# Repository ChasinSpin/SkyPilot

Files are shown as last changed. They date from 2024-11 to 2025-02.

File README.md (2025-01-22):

# Project SkyPilot

## Introduction

Project SkyPilot is a project to design / build / retrofit the C14 in the Wilson Coulee Observation dome with custom goto capabilities.  It leverages all the good parts of the existing mount (Ed Byers Gearing, Fork Mount etc.), whilst bringing it up to date with modern capabilities like:

* Goto (Catalog objects, RA/DEC etc.)
* Computer control
* Mobile phone/tablet control
* Faster slews
* Accurate tracking
* Auto guiding
* Astrophotography
* Dome control

*Although it provides automation, this is not a remote observatory due to safety and the potential for equipment to get damaged, other than control from the site itself.*

## Site

* [Card Access System](auth/README.md)
* Weather - TBA

## Dome:

Access to the dome and C14 is via a $30 yearly fee and instruction on how to operate the dome and C14's goto.

### Users:

* [C14 Goto](goto/README.md)
* C14 Astrophotography - TBA
* [Slit Alarm](dome/SlitAlarm/README.md)
* [GPS](dome/GPS/README.md)
* [PiFinder](pifinder/README.md) (Temporary)

### Site Manager

* [C14 Maintenance](maintenance/C14Maintenance.md)

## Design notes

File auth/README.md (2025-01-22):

# Dome Access

Access to the dome is via an access key (card or fob). To obtain an access key (the first included in your dome fee), contact the Site Manager and arrange pickup.

Please keep the access key safe; if you lose it, the dog eats it, etc., you will be asked for a small donation to the club to get a replacement.

The touchpad for access is the black box with the LED light on the door frame, the area you touch is the "star constellation," not the LED.

Follow the operation instructions below carefully. All accesses are logged, and failure to lock up correctly will result in you being contacted and asked to return to the site immediately to resolve.

# Instructions

## Entering

1. Hold the card/fob for a second or two, flat to the constellation star pattern and a few millimeters away from the touchpad

2. LED will change to mostly on with the occasional flash-off

3. PUSH ON THE DOOR and then pull to open (this is needed because of the pressure of the door seal)

4. Your name will be displayed on the small lower display just inside by the door

5. The door is now unlocked until you relock it, and you can move in and out by just pushing the door.  In this mode (open), it takes very little force to open/close the door, this is normal.

6. Be aware that if there is wind, the door may blow open, put the latch on the door if this is an issue (you likely want to cool the dome/C14 down for viewing anyway)

## Exiting

1. Hold the card/fob for a second or two, flat to the constellation star pattern and a few millimeters away from the touchpad

2. LED will change to mostly off with the occasional flash-on

3. PUSH IN THE DOOR and then pull to check it’s closed (this is needed because of the pressure of the door seal)

4. The door is now locked and armed

5. If you leave without closing correctly, an alarm will be sent to the Site Manager after a period, which will likely result in a phone call to you, and you’ll be asked to go back and lock up.

## Handing Over To Another

If you opened the dome, and someone else is closing, then when you leave, swipe to close yourself and have the person that’s taking over swipe to open.  That way, you’re logged out, and the next person is logged in. Locking up the dome correctly is now the responsibility of the next person.

Never hand over to someone who isn't an authorized dome user.

## Notes

1. The touchpad is on a 3-second lockout so that you can’t enter and exit at the same time.  I.E. After you’ve tapped, if you remove your key card, you have to wait 3 seconds before presenting another or the same card.

2. Currently, you tap to unlock and relock rather than tap every time you open the door like other systems you’ve likely encountered.  The reason is that we don’t want anyone locked out with their vehicle keys or keycards within the building.

3. For fire purposes, anyone inside can always get out by depressing the handle on the inside.

4. There’s an override key in case there's a hardware failure to get in conventionally.  Eric has the location information for the key if needed.

5. On power failure, the system is locked, and a conventional key needs to be used.

6. When using the dome, please do not unplug the system, and check that no one has unplugged it before you leave. The flashing LED on the touchpad indicates the system is powered

7. Cabling will be covered when I get time to make it look cleaner; in the meantime, please don’t rest any chairs against the gear, etc.

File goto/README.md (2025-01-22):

# Goto Notes

## Mount Operation

1. Make sure Dec Drive on forks is pointing East at right angles to the RA base with DEC cable wrapped behind
2. Power on mount
3. Slew to Dec 90 and press "Home Reset"

### SkySafari

1. Goto/Controls changes the slewing speed

## Byers RA Steppper Motor

* [Part Number: 3008-002](https://www.hurst-motors.com/asabsgeared.html)  Reduction ratio 150:1 12V Unipolar
	
	Current: Worm gear has 216 teeth, and the worm gear rotates once evey 6.6666 minutes, sidereal rates is 1440.091s/day.  This is 1.6666 degrees of rotation per tooth (360/216).
	Drive Gear from motor to worm seems like a 2:1 reduction (needs measuring) and drive contains a 150:1 reduction, so total reduction = ~150 x 2 x 216 = 64800:1
		
	* [Drive Link](https://www.cloudynights.com/topic/285415-byers-c14-starmaster-drive-retrofit/)

	* [Telescope Drive Comparisons](https://www.dfmengineering.com/news_telescope_gearing.html)

These are just notes, nothing of any relevance:

* [Dome Control](https://stargazerslounge.com/topic/407704-control-of-dome-to-keep-telescope-in-centre-of-slot/)

## DEC

Strainwave Drive Hollow HBK17 100:1 10arc second backlash
https://www.aliexpress.us/item/1005005920547351.html

Likely a ZWO version of LHS-17-100-CL-III
https://www.leaderdrive.com/strain-wave-gears/lhs-standard-hollow-shaft-flexspline-strain-wave-gear-lhs.asp

*UPDATE THIS*

Nema 17
B62MXL belt 10mm?  Measure and measure the gears in the AM5
Belt:  B62MXL10RF

No brake on Dec

RA: 17D4401-19BK Bipolar (Nema 17)
    • Phase Reistance: 2.30-2.35 Ohm
    • Phase Inductance: 3.7mH @ 1KHz
    • Double shaft with nut on one end: 5mm Diameter
 DEC: 14M3404 Bipolar (Nema 14)
    • Phase Resistance: 7.09-7.21 Ohm
    • Phase Inductance: 7.8-7.9mH @ 1Khz
    • Single shaft: 5mm Diameter, 22mm high

Stepper Drivers: Trinamic TMC5130A-TA 2.5A 5-46V 256 micro step https://www.trinamic...eet_Rev1.18.pdf

Strainwave gear 100:1

Center points are opto interrupted
Reduction 300:1   Stainwave + synchronous belt
Periodic Error <+- 20”
PE Duration 432s
Load Capacitor 13kg
Slew 6 deg/s

Hollow type

https://www.omc-stepperonline.com/hht-series-harmonic-drive-gearbox-70mm-ratio-100-1-backlash-20arcsec-8mm-input-diameter-hht-14-100-i-d8

# Uploading Firmare

1. Open OnStepX.ino in firmware/OnStepX using Arduino 2.3.2
2. Select the port for the Teensy 4.1
3. Connect USB to the Teensy
4. Board should be set to Teensy 4.1
5. Board Settings: Optimize: Faster, CPU Speed: 600MHz, USB Type Serial
6. Compile firmware and upload

## To Wipe NV Ram

Set NV Wipe in Extended.config.h and upload, wait 2 mins, then upload again with NV Wipe Off.

# Mount Startup

1. Set date/location
2. Unpark mount.  (Mount will not be in tracking mode)
3. Slew to NCP
4. Click Home Reset
5. Enable tracking
6. Slew

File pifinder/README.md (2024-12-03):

# PiFinder

## WCO Usage Instructions

*Note: PiFinder is a push-to solution, primarily until the Goto solution is fully implemented. After that, I may remove PiFinder from the scope and use another solution or integrate it into the Goto, that decision hasn't been made yet.*

* **DO NOT:**
	* Remove PiFinder from its' mount, knock or bump it, we want alignment to be maintained for the next user
	* Attempt to use PiFinder without training. PiFinder is password protected, and this is provided at the end of the training.
	* Change any settings other than the settings accessed via the device buttons on the device itself
	* Adjust Focus

## Setup

* Make sure PiFinder has the GPS cable connected and the cable is located such that it cannot be caught by the user as the cable is thin and can be damaged
* Connect USB Power Adapter
* Power on PiFinder and wait for the display to show a menu
* Remove lens cover
* Enter 4 digit pin provided to you, to enable the panel buttons

## Alignment (if needed)

* Put a bright star in the center of the eyepiece
* On "Camera" Screen, press the action button (looks like a STOP symbol, bottom right hand corner of the keypad), and select the same star by pressing the correct number that matches the star. The C14 and PiFinder axis are now aligned

## Connecting Via Sky Safari 7 (Plus or Pro) and selecting target

* Connect to the Wifi PiFinderAP (there's no password).  Note: Androids often need you to wait until a popup appears for the network confirming connection to a network without internet
* Click Scope and Connect in Sky Safari
* Make sure "Lock" is on, so that the screen automatically updates to the telescope position 
* Select target and click Goto. PiFinder comes up with a "Push", press the right arrow on the PiFinder.  Alternatively you can just slew to the target by moving the C14 and watching the current position in SkySafari

## Selecting Target on PiFinder Buttons

* Select "Objects"
* Find the object and press the right arrow

## Moving The Telescope

The PiFinder updates it's position (Alt/Az) when moving the telescope during which the screen is a bit dimmer.  When stationary, a photo is taken, plate-solved, the position updated and screen goes brighter.  A plate-solve always give you an accurate distance to the target.

The arrows are Alt/Az arrows not RA/DEC so can take a bit of practice to get used to, and they are inverted in direction sometimes, so just minimize the numbers on the screen so they are close to zero until you have the object in the eyepiece.

It's possible to get on target without looking through the eyepiece.

## Finish

* Cover lens with lens cover
* Disconnect GPS wire and put in ziploc bag
* Put cover back on GPS connector
* Remove Power adapter from the USB lead and place in ziploc bag
* Place ziploc bag back in the cupboard
* Wrap Grey USB cable losely around the PiFinder without bumping the PiFinder

## SkySafari 7 (Plus and Pro)

PiFinder can also be used with SkySafari on your mobile device via Telescope Control. Telescope Control is only available in SkySafari 7 Plus and SkySafari 7 Pro.

PiFinder will only be available in SkySafari AFTER the 4 digit pin has been entered.

To setup:

* Menu / Settings / Telescope / Presets / Click "Add Preset"
* Select "Other"
	* Mount Type: Alt-Az. GoTo
	* Scope Type: Meade LX200 Classic 
	* Click "Next"
	* IP Address: pifinder.local
	* Port Number: 4030
	* Connect to the PiFinderAp Network in your phones settings. Note: Androids often need you to wait until a popup appears for the network confirming connection to a network without internet
	* Click on "Check Connection Now"
	* If connection verified, click Next, otherwise check the network you're connected to
	* Change Preset name to "PiFinder"
	* Make sure "Set Telescope Time & Location" is UNCHECKED
	* Click "Save Preset"
	* Select "PiFinder" and connect
	* Click on Observe / Scope Display and enable Telrad Circles and Cross Hairs so you can see a target for the current C14 position in SkySafari

A graphical representation of setting up on SkySafari can be found here: [PiFinder SkySafari Setup Instructions](https://pifinder.readthedocs.io/en/main/skysafari.html)

# Everything Below This Point Are Developer Notes:

## Install

* Image PiFinder_2.0.4.img:
	* Set username and password:
		* Username: pifinder
		* Password: <choose>
* Boot PiFinder, screen will have logo on for a few seconds, then disappear, then it will come back, wait for menu to appear.
* Connect to PiFinderAP with WiFi
* ssh pifinder@pifinder.local
* sudo raspi-config
	* Select 3 (Interace Options):
		4: SPI and choose Enable
		5: I2C and choose Enable
* On PiFinder Front Panel:
	* Settings / PiFinder Type: Left
	* Settings / Mount Type: Equatorial
	* Settings / Camera Type: v3 - imx296 cam
	* Settings Wifi Mode: Client
	* Settings Wifi Mode: Access Point
* ssh pifinder@pifinder.local
	* Change main.py in PiFinder/python/PiFinder to add PIN as per CodeChanges
* ssh pifinder@pifinder.local
	* Enable Overlay FS to avoid SD Card Corruption (see below)

**IMPORTANT: PiFinder MUST ALWAYS BE SHUTDOWN IF OVERLAY FS IS OFF TO PREVENT SD CARD CORRUPTION**

## Switch Overlay FS On (Write Protection)

* sudo raspi-config
* Performance Options / Overlay File System:
	* Would you like the overlay file system to be enabled?: Yes
	* The overlay file system is enabled: Ok
	* Would you like the boot partition to be write-protected?: Yes
	* The boot partition is read-only: Ok
	* Finish
	* Reboot

## Switch Overlay FS Off (Writable)

This is a 2 step process, step 1 to switch off the overlay file system and step 2 to switch off boot partition write protection.

* sudo raspi-config
* Step 1: Performance Options / Overlay File System:
	* Would you like the overlay file system to be enabled?: No
	* The overlay file system is disabled: Ok
	* The boot partition is currently read-only. This cannot be changed while an overlay file system is enabled. Ok
	* Finish
	* Reboot
* Step 2: Performance Options / Overlay File System:
	* Would you like the overlay file system to be enabled?: No
	* The overlay file system is disabled: Ok
	* Would you like the boot partition to be write-protected?: No
	* The boot partition is writeable: Ok
	* Finish
	* Reboot

## PiFinder Development

sudo systemctl restart pifinder

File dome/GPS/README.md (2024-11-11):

# GPS

## Introduction / Usage

**Please replace the yellow connector covers when connectors are not in use to prevent corrosion or dust.**

The dome now has 2 external active GPS antennas, which are available for connecting to, located on the pier, primarily for time and timing purposes. 

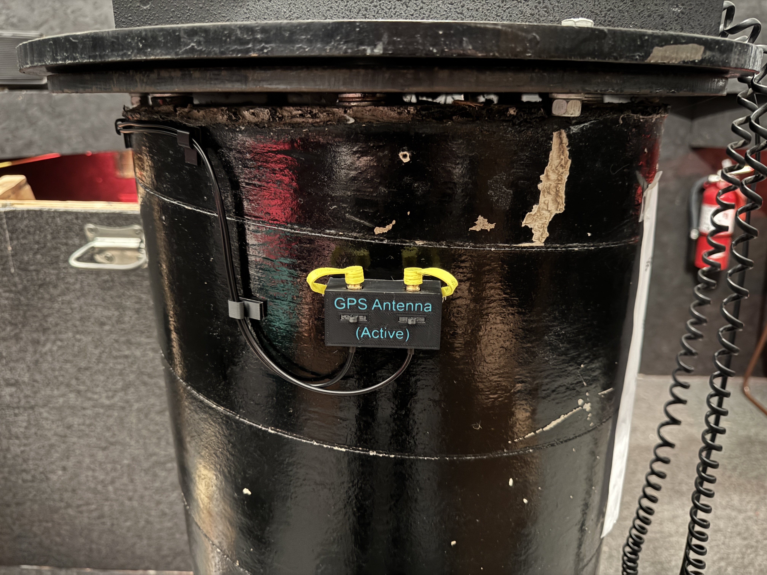
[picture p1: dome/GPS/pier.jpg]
GPS Antenna On Pier


Because the dome is made of metal, it's difficult to get a reliable GPS signal within the dome without an external antenna.

One connection is for the OnStepX Goto Mount Controller (to provide date/time), and the second is for other use (typically Asteroid / Lunar Occultation Timing for Astrid or QHY174GPS). The connections end in an SMA Female connector, and a male-to-male SMA lead that will reach from there to the OTA can be found in a ziploc bag in the lens cupboard.

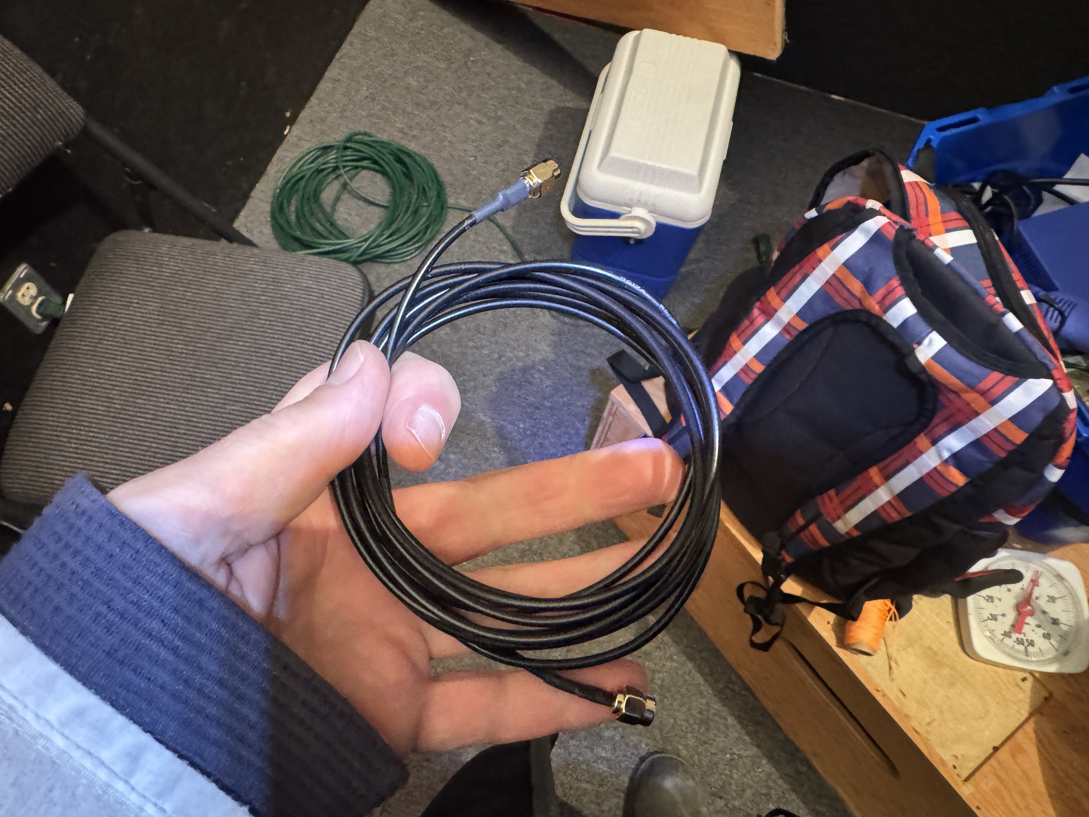
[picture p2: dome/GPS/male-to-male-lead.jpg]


## Repair

### Overview

The antennas are located on the exterior to the left above the door, wired around the inside of the door frame and into the room underneath the dome, across the ceiling, and up the pier. 

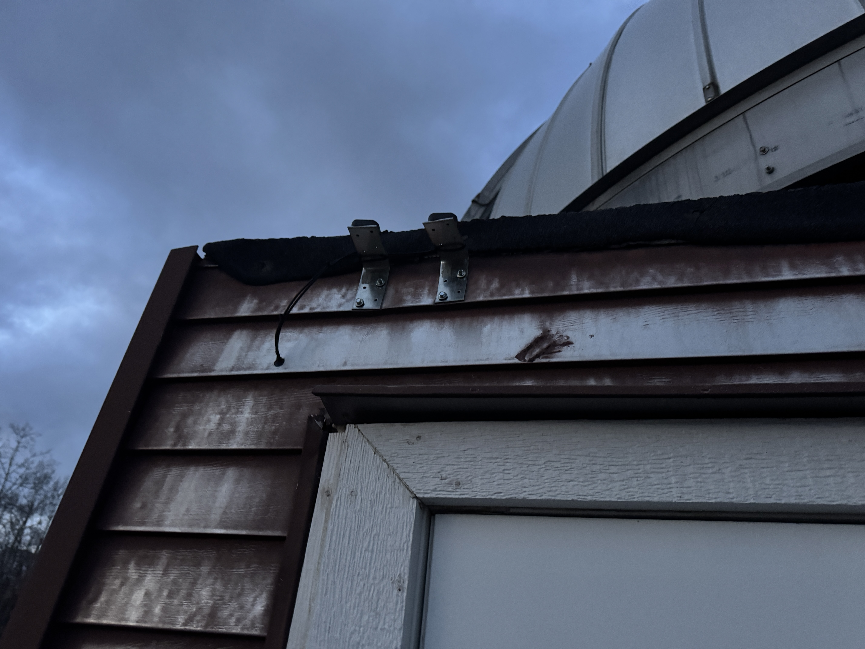
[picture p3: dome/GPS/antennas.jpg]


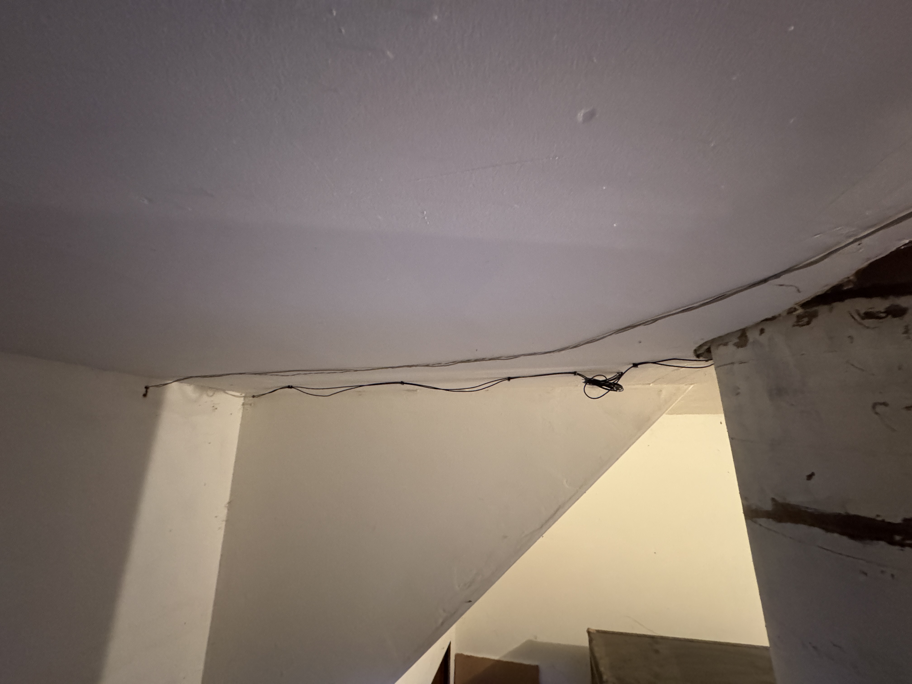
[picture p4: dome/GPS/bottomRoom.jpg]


### Antenna Replacement
 
There is a Male/Female SMA connector on each lead that's covered in heat shrink that can be found midway down the lefthand side of the door frame looking from the inside.  This is the connection point to replace the Active GPS Antenna, if it ever gets damaged by Hail etc.  Purchase information for the GPS antenna is:  [Bingfu Vehicle Waterproof Active GPS Navigation Antenna with SMA Male Connector](https://www.amazon.ca/dp/B07R7RC96G).  If the antennas are replaced, please be sure to recaulk the holes.

### Pier Connector Damage

The pier connectors contain a male-to-female adapter as a sacrificial connector in case of damage [Boobrie SMA Male to SMA Female Connector](https://www.amazon.ca/dp/B07FKNMPKD). To replace, use a pliers or piece of wire to pull out the tab holding the connector assembly in place and pull the wire out from the bottom, the connector will follow. Ensure new connector is tight and that all the Hex Nuts are in line with each other. Test fit the tab before placement, and put tab in after placement.

### 3D Printed Parts

3D printed files can be found in this folder. Clips and Bracket are mounted with 3M Extreme Mounting Tape. Bracket uses 2 x M3 Threaded Inserts, and 2 short M3 bolts and washers to attach the TPU covers to the the sides.

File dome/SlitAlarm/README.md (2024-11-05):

# Slit Alarm

## Introduction

In bad weather or in case of equipment failure, the motor controlling the slit in the WCO dome can re-engage if power is left on to the slit.  This can lead to significant damage (motor burnout or worse).

It is quite common for power to be left on by users due to forgetting to return the slit switch back to neutral after the bottom limit switch has been reached and the movement has stopped.

## Alarm

An alarm has been installed to solve this issue and consists of a 110V AC buzzer and red light, which activates during slit closure.  If the user forgets to switch off the slit power by returning the switch to neutral, the buzzing continues as a reminder to the user to return the switch to normal.  It only activates on slit closure, not on opening, it is up to the user to remember on opening, as the user is present, this is less critical than after the user has left.

The alarm has been installed in an external metal box that is grounded to the main switch box. The 110V for the switch is supplied via 2 contacts in the main switch box, which are engaged to 110V when the slit is being closed. The part number for the alarm is [uxcellAC/DC 110V 20mA Equipment Alarm Signal Indicator Light Flash Buzzer](https://www.amazon.ca/dp/B015SK2OM8?ref=ppx_yo2ov_dt_b_fed_asin_title) and is CE rated.

https://github.com/user-attachments/assets/1f60c342-2444-4560-9f1b-39a3ea6fde14

Photo of the inside of the alarm box. Box contains 110V to the switch + Ground to the box, To remove power, unplug the lead powering slit.  Electrical tape has been added to cover a small part of the exposed ring terminal if the case is open.  Buzzer is place on top and under a wooden overhang to prevent bumping by users when push items like the stairs around the dome.

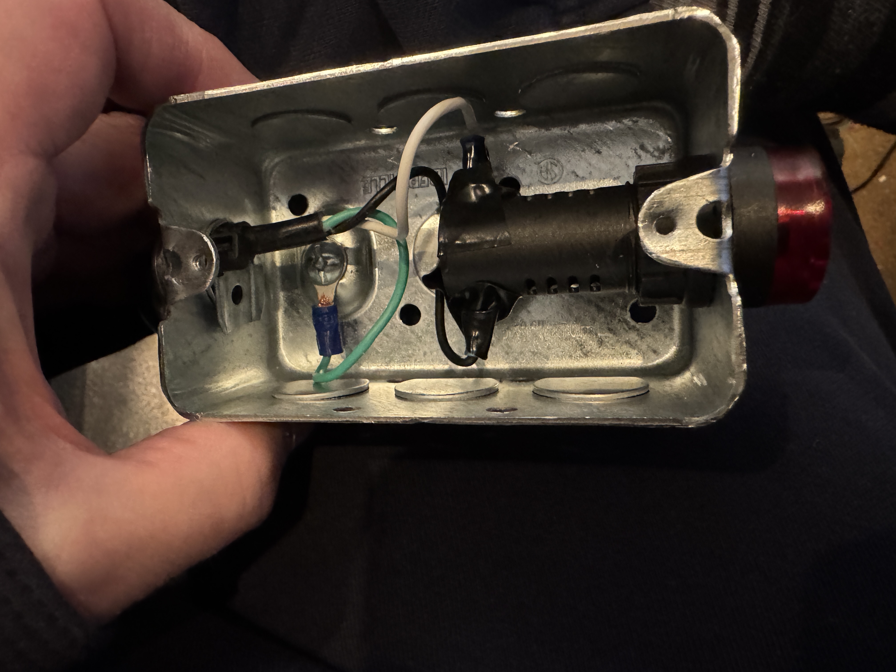
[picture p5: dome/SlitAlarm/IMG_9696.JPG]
Inside Box


Please note that if servicing the main switch, the metal case is grounded by a lead and ring terminal that is trapped between the case and case screw (same as before).  Important to ensure this ring terminal is installed correctly to maintain grounding on both the switch case and the alarm case.  Always check grounding to both cases after reassembly.

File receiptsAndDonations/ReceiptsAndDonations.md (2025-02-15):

# Wish List (Astrophotography)

The following is a list of items that will improve the club's C14 as a resource for astrophotography and outreach / member use.  If you can help in anyway, it would be appreciated by members.

## Phase 1 - Add "Goto" to the C14 (Completed)

Build a custom goto system for the C14 to turn manual operation into automated with goto and auto-guiding capability.  Designed by Mark Simpson using 3D printed parts and a strainwave gear for declination, it leverages the manual mount/fork structure for durability and adds motion to both axis.

This phase has been completed.  Resolution is 0.25 arc seconds, and guiding is 0.5 arc seconds which is better than the 2 arc seconds needed for astrophotography.

## Phase 2 - Plate Solving (Completed)

Plate solving is needed for accurate targeting of objects. This phase uses a guide camera on the Orion ST80 combined with an ASIAIR to provide plate solve ability. When Phase 2 is complete, the guide camera will be repurposed into a guide camera and the main camera will be doing the plate solving. 

| Item | Price | 
| ---- | ----- |
| [ZWO ASIAIR PLUS 256GB (ZWO-AIRPLUS-256)](https://all-startelescope.com/products/zwo-asiair-plus-256gb-zwo-airplus-256) | $424.58 |
| [ZWO ASI174Mini Monochrome Astronomy Camera (ASI174MINI)](https://all-startelescope.com/products/zwo-asi174mini-usb2-0-mono-asi174mini) | $566.58 CAD | 
| [ZWO Finder Shoe for ASIAIR PRO and Guide Scope (ZWO-FS-II)](https://all-startelescope.com/products/zwo-zwo-fs) | $25.56 CAD |

This has been donated to the club by Daniel and Nancy Boychuk.

## Phase 3 - Astrophotography (Completed)

This is to be used on C14 main optical axis @3910mm and @2300mm (with f/6.3 focal reducer). It's a one shot color (OSC) camera. It provides the ability for club members to take astrophotography data/images/scientific research on the clubs C14.

| Item | Price | 
| ---- | ----- |
| [ZWO ASI2600MC Pro  ASI2600MC-P](https://all-startelescope.com/products/zwo-asi2600-pro-usb3-0-cooled-color-astronomy-camera-asi2600mc-p) | $2128.58 CAD |
| **TOTAL (inc. shipping and tax)** | $2289.61 CAD |

Additional to this phase is the flat panel which has already been purchased via club donations, when it was on discount at Christmas.

## Phase 4 - Add Accessibility and Outreach, Cold Weather Tours, Widefield Astrophotography (Completed)

The astrograph will be piggybacked on the C14 and provides widefield capability for imaging at 264mm focal length and f/4.8.

It also adds the capability for outreach and accessibility, as the output of the camera attached to the astrograph, can be streamed to the clubhouse large screen TV and a TV screen inside the dome.

The aiming-device is a pan/tilt for the astrography to align it with the main optical axis.

| Item | Price | 
| ---- | ----- |
| [Askar SQA55 Quintuplet Refractive Astrograph](https://all-startelescope.com/products/askar-sqa55-quintuplet-refractive-astrograph-sqa55) | $1079.95 CAD |
| [ADM Mini-MAX ALT/AZ Aiming Device. Male Dovetail Version](https://www.admaccessories.com/product/mini-max-altaz-aiming-device-male-dovetail-version/) | $339.00 USD ($574.58 CAD) |
| **TOTAL (inc. shipping, tax, duties)** | $1872.55 CAD |

## Phase 5 - Add Narrowband (HA, SII, OIII) on C14 and Widefield (Completed)

There are newer filters now available which can provide good narrowband imaging on one shot color cameras.  This setup is for 2 filters (HA/OIII dual band and SII/OIII dual band) than can be used to provide 3 band data for narrowband imaging.

Narrowband imaging produces sharper and better imaging for Planetary Nebula, Emission Nebula and Planetary forming regions of Galaxies.

Narrowband imaging is immune to light pollution and moonlight:

* WCO is in Bortle 5 skies (which is fairly heavy light pollution), in narrowband, targets are the same as if you were in a bortle 1 or 2 skies. It's possible to image also in the northern part of the sky, or towards Okotoks, where the light domes are worse.
* It's possible to image during a full moon without gradients when positioned at least 90 degrees away from the moon. The results are the same as a moonless night.

The following are the 2 filters, a bracket to hold the widefield scope and backfocus adjustment spacer for the imaging train.

| Item | Price | 
| ---- | ----- |
| [ADM Accessories Dovetail Plate Adapter (DPA)](https://all-startelescope.com/products/adm-dovetail-plate-adapter) | $82.95 CAD |
| [ZWO M48(male)-M48(female) extender (16.5mm length)](https://all-startelescope.com/products/zwo-m48male-m48famale-extender16-5mm-length-zwo-m48-ext16-5) | $32.66 CAD |
| [Askar Color Magic D Duo-Band Filters - D1](https://all-startelescope.com/products/askar-colour-magic-d-duo-band-filters-colour-magic-d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) | $401.95 CAD |
| [Askar Color Magic D Duo-Band Filters - D2](https://all-startelescope.com/products/askar-colour-magic-d-duo-band-filters-colour-magic-d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) | $401.95 CAD |
| **TOTAL (inc. shipping and tax)** | 983.87 CAD |

*Short by: $13.87*

## Phase 6 - Accessories (Completed)

Accessories to complete the system. Filters holders and drawer (3 for filters and 1 for blanking off for broadband). Celestron 48mm back focus assembly for native focal length imaging.  Flat Panel for piggybacked astrograph.

| Item | Price | 
| ---- | ----- |
| 3 x [ZWO Filter Holder V2](https://davidastro.com/products/zwo-filter-holder-v2) | See below |
| [ZWO Filter Drawer V2](https://davidastro.com/products/zwo-filter-drawer-v2-m54) | See below |
| [Celestron 48mm T-Adapter for EdgeHS 9.25", 11", 14"](https://davidastro.com/products/celestron-48mm-t-adapter-for-edgehd-9-25-11-and-14) | See below |
| Total David's Astro (inc GST and shipping) | $400.80 CAD |
| [M48x0.75 extension tubes](https://www.amazon.ca/dp/B0BSGHFX44?ref_=pe_125682630_1045605200_fed_asin_title) | $12.60 CAD |
| [Camera Holder/Cover](https://www.amazon.ca/dp/B00VZYRKNA) | $25.66 CAD |
| [SCT-M48 Adapter - Williams Optics - D-SCT-TA](https://williamoptics.com/products/sct-m48-adapter?_pos=1&_sid=63479adb4&_ss=r) | $96.48 CAD ($67.00 USD exchange rate 1.44) |
| [Astrophotography 5in EL Panel Circle Flat Frame Kit]() | $194.40 CAD |
| **TOTAL (inc. shipping and tax)** | $729.94 CAD |

## Phase 7 - Electronic Focusing (Completed)

To simplify focusing in general and to achieve pinpoint focusing for astrophotography (which is hard to achieve manually with a 14" SCT), it would be beneficial to have electronic focusing for the C14 and piggybacked Sharpstar 76 EDPH.

For the C14, as it's visual too, we would require a hand controller. For both scopes,  temperature sensors would be useful to trigger automatic refocusing on temperature changes.

| Item | Price | 
| ---- | ----- |
| 2 x [ZWO EAF 5V Electronic Automatic Focuser (ZWO-EAF-5V)](https://all-startelescope.com/products/zwo-eaf) | $423.16 CAD |
| 1 x [ZWO Temperature Sensor of EAF (ZWO-EAF-SENSOR)](https://all-startelescope.com/products/zwo-temperature-sensor-of-eaf-zwo-eaf-sensor) | $28.12 CAD |
| 1 x [ZWO EAF Bracket for Celestron C11 & C14 (ZWO-EAF-C11-C14)](https://all-startelescope.com/products/zwo-eaf-bracket-for-celestron-c11-and-c14-zwo-eaf-c11-c14) | $55.38 CAD |
| 1 x [ZWO Temperature Sensor of EAF (ZWO-EAF-SENSOR)](https://all-startelescope.com/products/zwo-temperature-sensor-of-eaf-zwo-eaf-sensor) | Donated by Jerry |
| 1 x [ZWO Hand Controller for EAF (ZWO-EAF-HC)](https://all-startelescope.com/products/zwo-hand-controller-of-eaf-zwo-eaf-hc) | Donated by Jerry |
| **TOTAL (inc. shipping and tax)** |  $275.94 CAD |

All-Star Telescope have paid for 50% of the items in Phase 7.

## Other
| Item | Price | 
| ---- | ----- |
| iPad for those that don't have iPhones | an older iPad is fine |
| Charger |  |

# Donations

| Person | Date | Item | Amount |
| --- | ---- | ---- | --- |
| Khalid Qureshi | 2024-11-27 | 50% Flat Panel and $25.65 towards strainwave gear for DEC| $200.00 |
| Vinh Vo | 2024-11-28 | 50% Flat Panel | $174.35 |
| Alan K Chan | 2024-12-02 | Part payment towards OnStepX Controller components | $125 |
| Mike Rossier | 2024-12-23 | Part payment towards strainwave gear for DEC | $150.00 |
| Daniel & Nancy Boychuck | 2025-01-29 | ASIAIR Plus 256, ASI174MM, Finder Shoe | $1086.99 (via donation to club) |
| Mike Rossier | 2025-01-31 | Part payment toward Askar Filter - D1 | $250.00 |
| Jerry Medeiros | 2025-02-01 | Part payment towards Askar Filter - D1 and D2 | $300.00 |
| Vinh Vo | 2025-02-01 | Part payment towards Askar Filter - D2 | $120 |
| Eric Klaszus | 2025-02-01 | Part payment towards Askar Filter - D2 | $200 |
| Alan K Chan | 2025-02-02 | ADM Adapter Plate and M48 Extender | $100 |
| Terry Martin | 2025-02-02 | Various items. ZWO 2600MC-Pro, Sharpstar 76EPDH + Focal Reducer, Alt-Az Mount, Vixen, L-Extreme, Rings, M54 Adapters | $4824.22 |
| Submitted to Nisha - up to this point | - | - | - |
| Jerry Medeiros | 2025-02-13 | Focuser Hand Controller and temperature sensor | $84.78 |
| Bill Yeung | 2025-02-13 | Payment of Phase 6 + Phase 7 and $26.41 towards magnetic charging cable| $1032.29 |
| Mark Simpson | 2024-11-01 - Present | SkyPilot Goto | $1069.36 |
| All-Star Telescope | 2025-02-14 | 50% Towards Phase 7 | $246.30 |
| Trevor Gauthier | - | Planetary Camera | TBD |
| Bruce Foster | - | f/6.3 Japan Focal Reducer | TBD |
| Maciek | - | Airplay units for Android | TBD |
| **TOTAL** | | | $9716.99 |

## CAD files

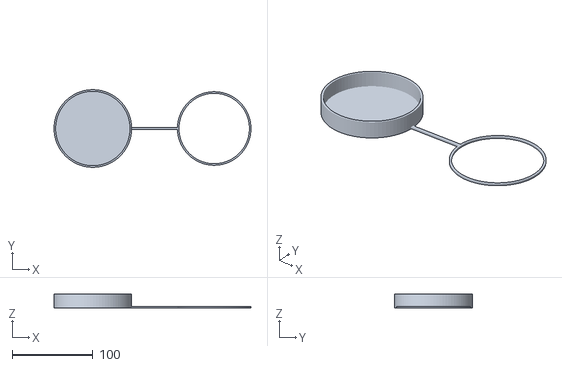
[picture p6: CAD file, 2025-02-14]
dome/C14SilverFinderScopeCover/C14SilverFinderScopeCover.stl
243.5 x 96.0 x 17.0

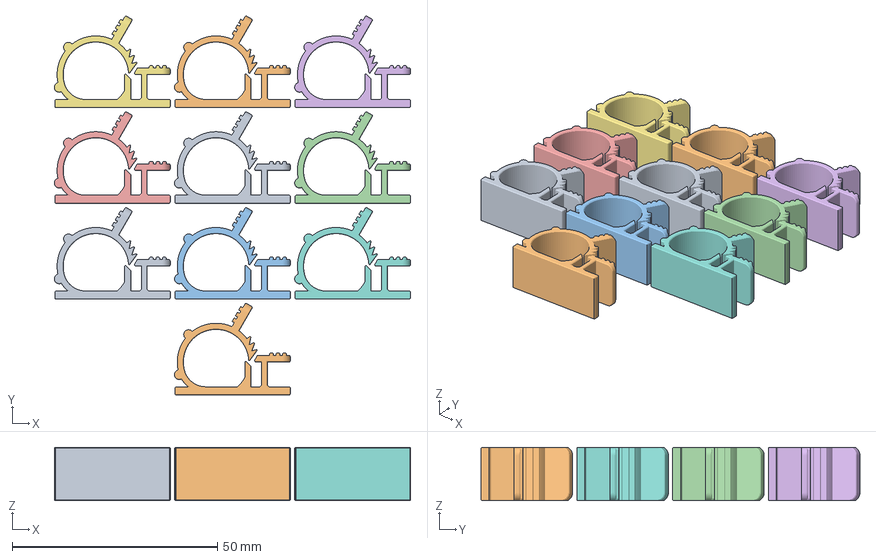
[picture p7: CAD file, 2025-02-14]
dome/CableClip/small wall clip v1.3mf
86.9 x 92.4 x 13.0 mm

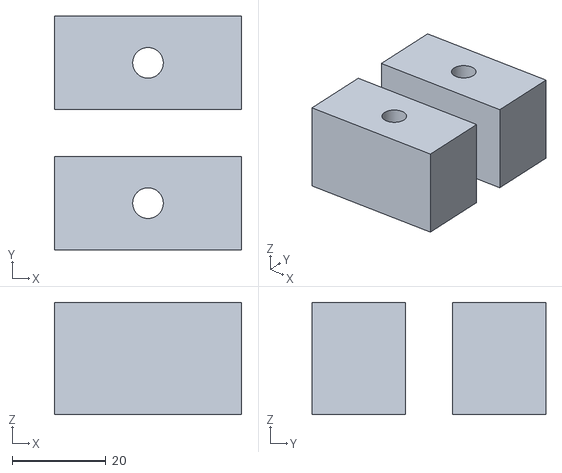
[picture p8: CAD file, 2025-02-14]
dome/CGERailEndStop/CGERailEndStop.stl
40.0 x 50.0 x 24.0

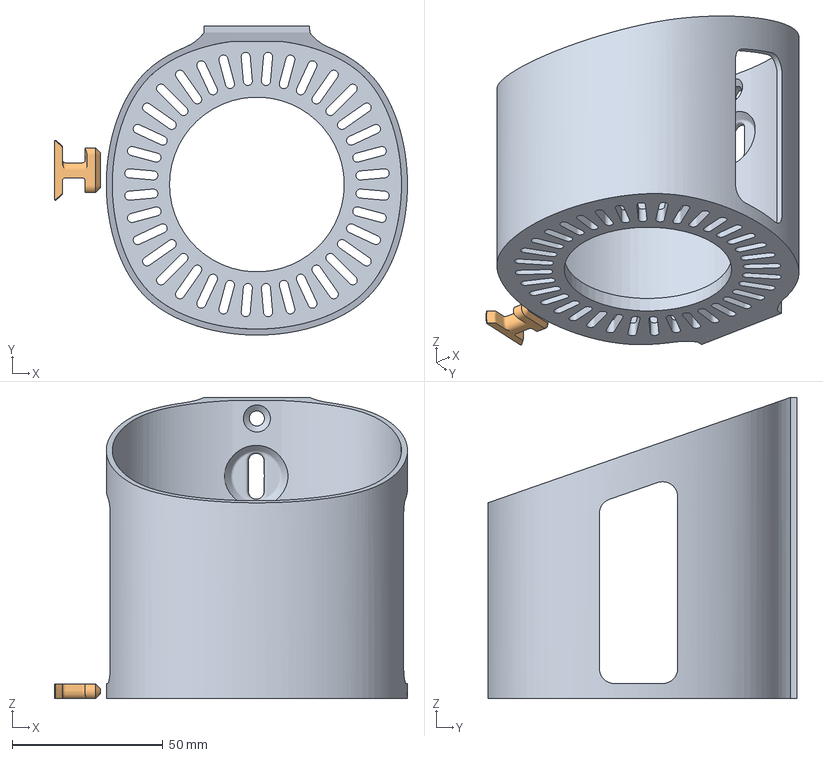
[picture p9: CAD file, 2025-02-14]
dome/DecoM4/DecoM4Holder.3mf
117.2 x 102.7 x 100.0 mm
TP+Link+Deco+M4+T-Clip+Skadis+Holder.stl
T-Clip for Painted Skadis (Flush).STL

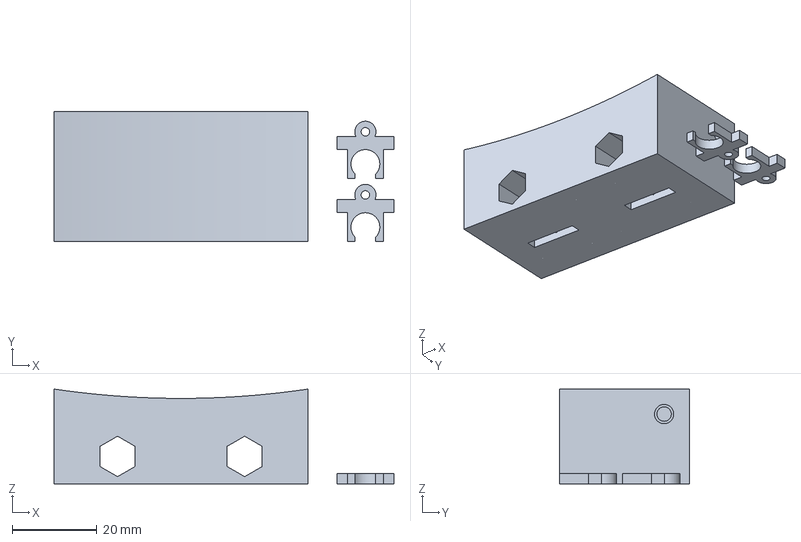
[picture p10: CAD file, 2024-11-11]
dome/GPS/GPSBracket.3mf
80.2 x 30.7 x 22.4 mm

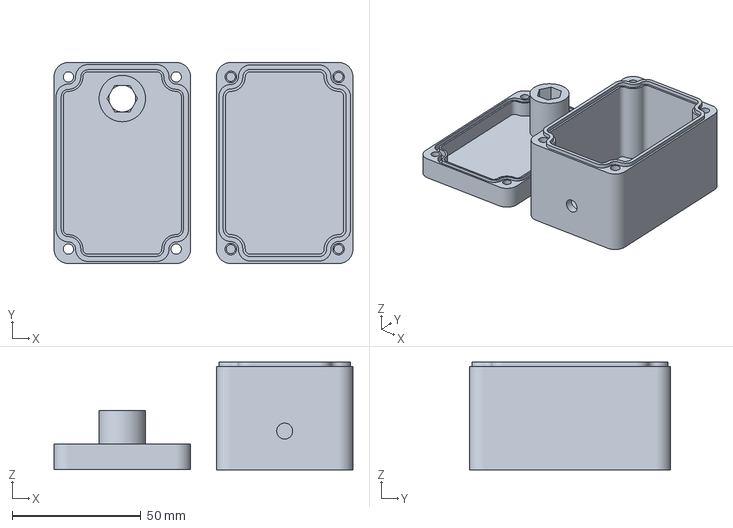
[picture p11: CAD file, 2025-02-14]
dome/Power12V/Power12V.3mf
116.0 x 78.0 x 41.7 mm

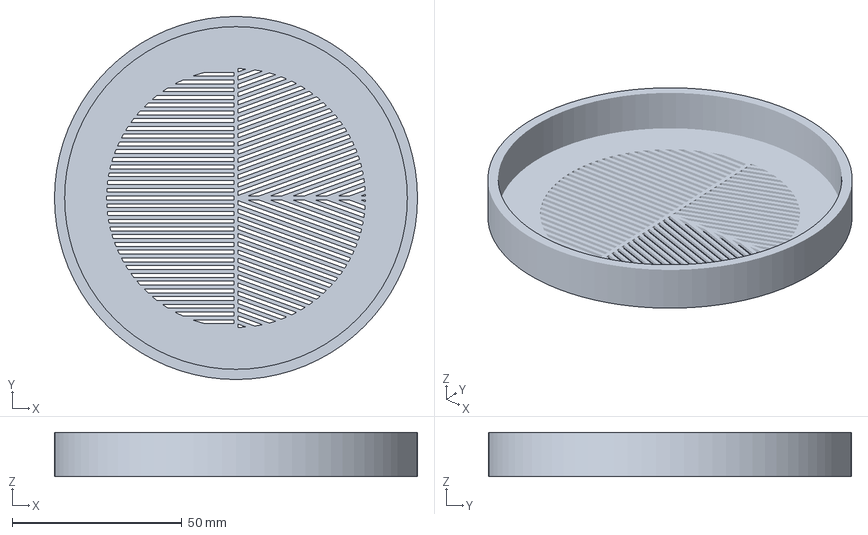
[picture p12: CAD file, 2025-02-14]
dome/Sharpstar76EDPHBahtinov/Sharpstar76EDPHBahtinov.3mf
107.0 x 107.0 x 13.0 mm

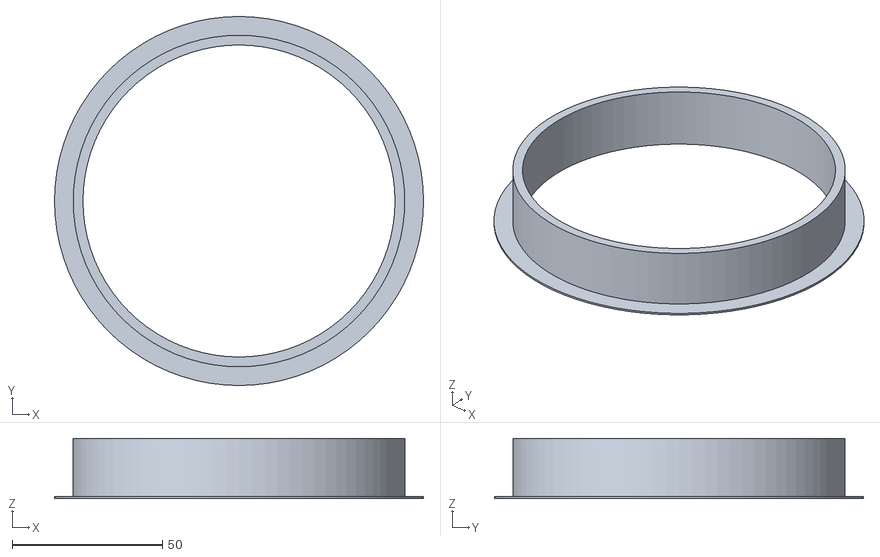
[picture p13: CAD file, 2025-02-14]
dome/TriBahtinovMask_ClubC14/TriBahtinovCenterSupport.stl
123.0 x 123.0 x 20.0

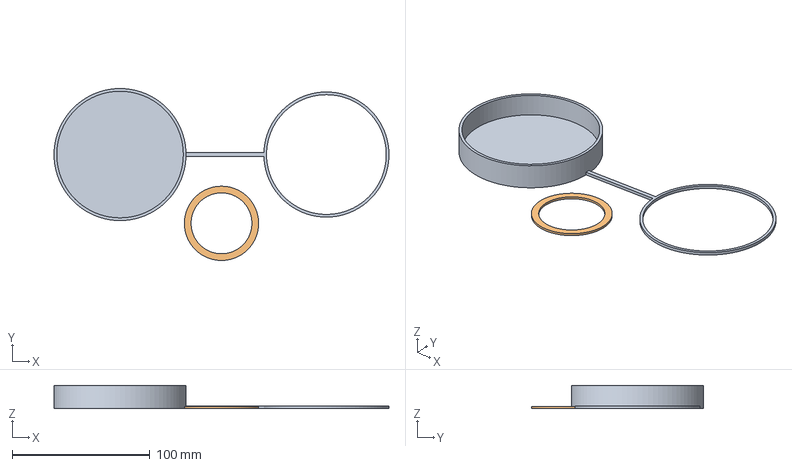
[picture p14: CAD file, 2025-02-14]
dome/ZWOCameraCoverGromit/ZWOCameraCoverGromit.3mf
243.5 x 125.0 x 17.0 mm
C14SilverFinderScopeCover.stl
ZWOCameraCoverGromit.stl

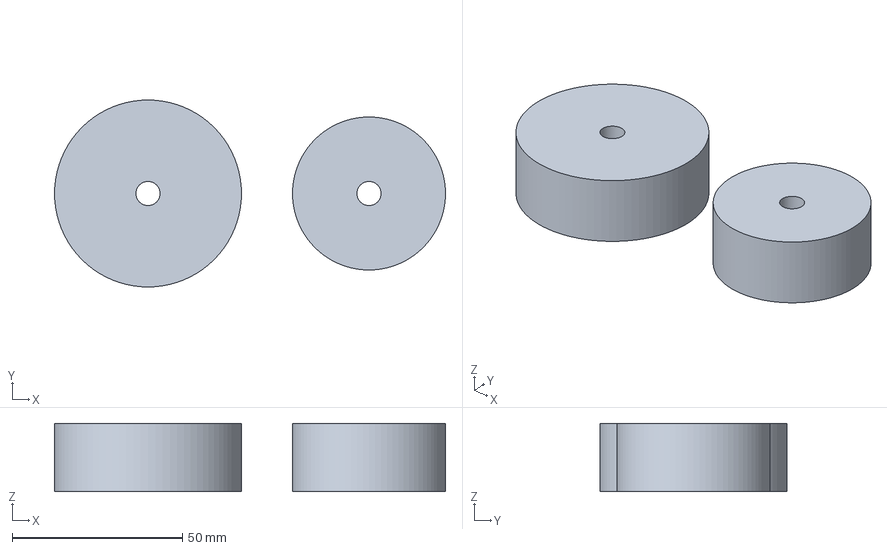
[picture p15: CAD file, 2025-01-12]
doors/DoorHoleFiller.3mf
115.0 x 55.0 x 20.0 mm

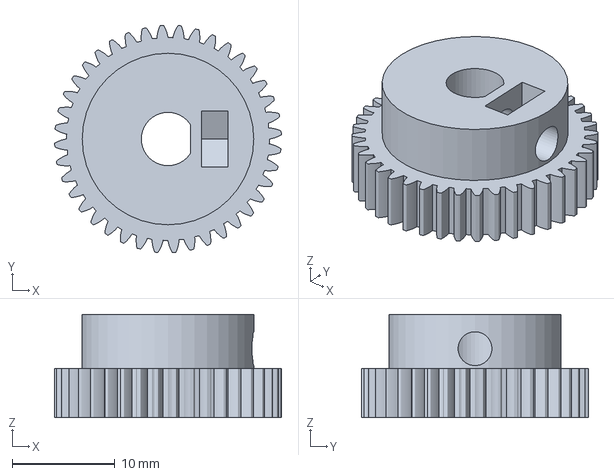
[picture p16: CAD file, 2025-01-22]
goto/3DPrinted/byersDriveGear.3mf
22.1 x 22.1 x 10.1 mm

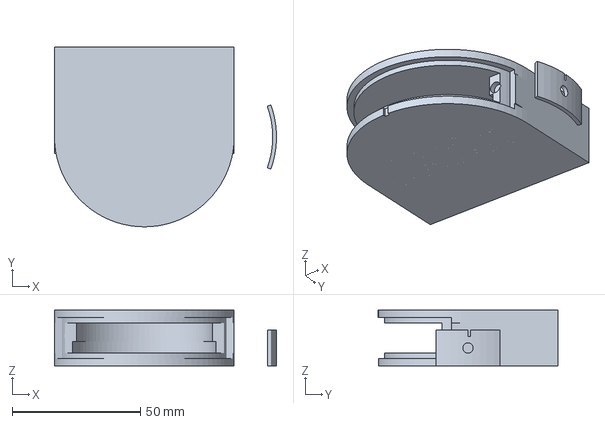
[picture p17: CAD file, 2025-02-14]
imaging/3DPrinting/ZWOFilterCase/ZWOFilterCase.3mf
86.5 x 70.0 x 21.8 mm

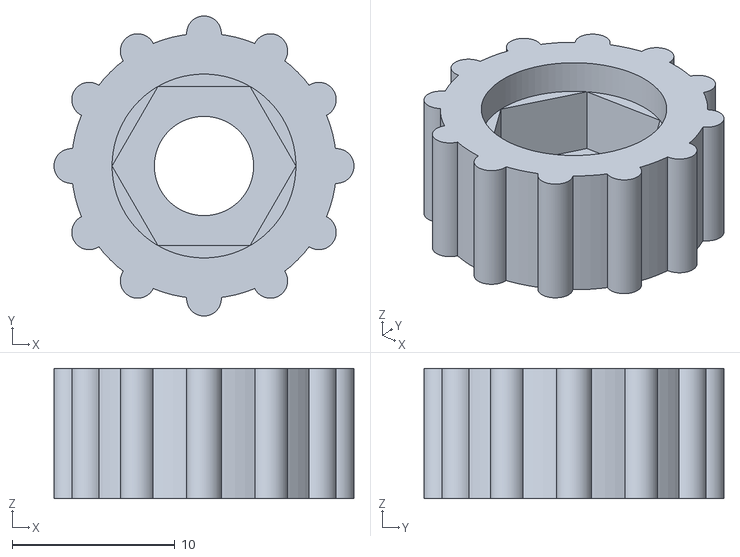
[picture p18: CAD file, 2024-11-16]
pifinder/3DPrinted/C14PiFinderHolder/knob.stl
18.4 x 18.4 x 8.00

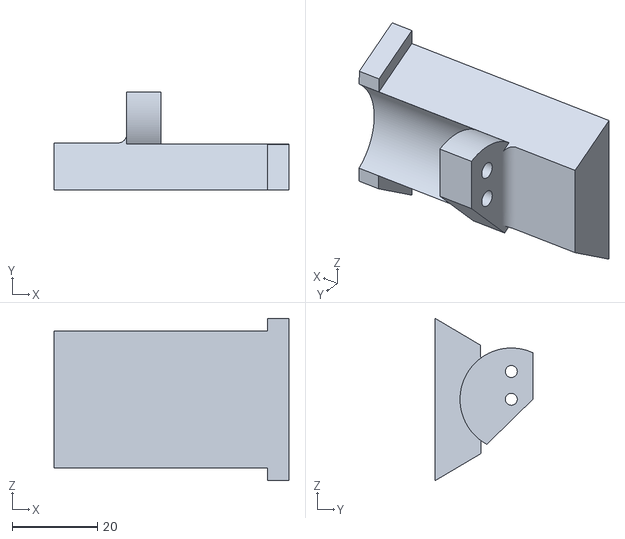
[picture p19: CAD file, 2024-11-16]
pifinder/3DPrinted/PiFinder/dovetail_bottom_hardstop_right.stl
55.0 x 22.9 x 38.0

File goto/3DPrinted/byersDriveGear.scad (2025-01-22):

// Generic PA with filament Taulman 645
//      100% fill
//      No Support
//      0.08 Extra Fine (layer height)
//      Smooth PEI Plate, use Glue Stick
//      Quality/Advanced:
//          Order of walls: Outer/Inner
//          Avoid cross wall: Checked
//          Avoid crossing wall max detour length: 50mm
//      Strength:
//          Wall Loops: 3
//          Sparse Infill Density: 100%
//          Sparse Infill Pattern: Rectilinear
//
// M3 Nut and grub screw
//
// Important, scale up model by 1.8% to allow for shrinkage
// Outer diameter should be 22.225mm

manifoldCorrection      = 0.01;
manifoldCorrection2     = manifoldCorrection * 2;



byersSpurGear(teeth=40, diametralPitch=48, pressureAngle=20.0, gearThickness=4.78, hubThickness=5.3, hubDiameter=16.73, boreDiameter=5.0+0.2, insertHoleDiameter=3.0+0.3, flangeInsertDepth = 0.4, retainingNutDiameter = 6.0 + 0.3, retainingNutThickness = 2.3 + 0.3, retainingNutOffsetX = -3.8, insertHoleOffsetZ = -0.7);



module byersSpurGear(teeth, diametralPitch, pressureAngle, gearThickness, hubThickness, hubDiameter, boreDiameter, insertHoleDiameter, flangeInsertDepth, retainingNutDiameter, retainingNutThicknessretainingNutDiameter, retainingNutThickness = 2.3 + 0.3, retainingNutOffsetX, insertHoleOffsetZ)
{
    difference()
    {
        union()
        {
            difference()
            {
                union()
                {
                    linear_extrude(gearThickness)
                        spur_gear(teeth, P = diametralPitch, pa = pressureAngle);
    
                    translate( [0, 0, gearThickness] )
                        cylinder(d = hubDiameter, h = hubThickness, $fn = 40);
                }
    
                translate( [0, 0, -manifoldCorrection] )
                    cylinder(d = boreDiameter, h = gearThickness + hubThickness + manifoldCorrection2, $fn = 40);
            }
        
            translate( [boreDiameter/2 - flangeInsertDepth, -boreDiameter/2, 0] )
                cube( [boreDiameter/2, boreDiameter, gearThickness + hubThickness] );
        }
        
        translate( [hubDiameter/2, 0, gearThickness + hubThickness/2 + insertHoleOffsetZ] )
            rotate( [0, 90, 0] )
                cylinder( d = insertHoleDiameter, h = hubDiameter + manifoldCorrection2, center = true, $fn = 40 );
        
        translate( [hubDiameter/2 + retainingNutOffsetX, 0, gearThickness + hubThickness/2 + insertHoleOffsetZ] )
            rotate( [0, 90, 0] ) 
            {
                cylinder(d = retainingNutDiameter, h = retainingNutThickness, center = true, $fn = 6);
                translate( [0, -retainingNutDiameter/2 * 0.865, retainingNutThickness/2] )
                    rotate( [0, 180, 0] )
                        cube( [10, retainingNutDiameter * 0.865, retainingNutThickness] );
            }   
    }
    
}

/**
    Constants
**/
in_to_mm = 25.4;
rad_to_deg = 180 / PI;
deg_to_rad = PI / 180;

/**
	Functions
**/
function parametric_points(fx, fy, t0=0, t1=10, delta=0.01) 
= [for(i = [t0:delta:t1]) [fx(i), fy(i)]];

function reverse(vector)
= [for(i = [1:len(vector)]) vector[len(vector) - i]];

/**
	Maths
**/
function calc_module(P) = in_to_mm / P;
function calc_addendum(P) = (1/P) * in_to_mm;
function calc_dedendum(P) = (1.25/P) * in_to_mm;
function calc_dp(N, P) = (N/P) * in_to_mm;
function calc_db(N, P, pa) = calc_dp(N,P) * cos(pa);
function calc_dr(N, P) = calc_dp(N,P) - 2 * calc_dedendum(P);
function calc_circular_pitch(P) = (PI / P) * in_to_mm;
function calc_thickness(P) = (1.5708 / P) * in_to_mm;
function calc_alpha(dp, db, pa) = ((sqrt(pow(dp,2) - pow(db,2))/db) * rad_to_deg - pa);
function calc_clearance(P) = calc_dedendum(P) - calc_addendum(P);
function calc_center_distance(N1, N2, P) = in_to_mm * (N1 + N2) /(2 * P);

/**
	Modules
**/
/**
    Given some parameters, this method will generate a spur gear
    with an involute curve. Accepted paramters include:
     - N = How many teeth
     - P = Diametral pitch (all gears should have the same P)
     - pa = pressure angle (recommended to remain at 14.5)
**/
module spur_gear(N, P = 12, pa = 14.5) {
    dp = calc_dp(N, P);
    db = calc_db(N, P, pa);
    dr = calc_dr(N, P);
    a = calc_addendum(P);
    b = calc_dedendum(P);
    c = calc_clearance(P);
    p = calc_circular_pitch(P);

    // Undercut adjustment
    // NOTE: this might not be great? IDK
    undercut = 1 * c;

    // Calculate radius to begin the involute calculations
    r = (db - undercut) * .5;
    alpha = calc_alpha(dp, db, pa);
    beta = ((360 / (4*N)) - alpha) * 2;

    module involute_tooth() {
        x = function(t) (r * (cos(t*rad_to_deg) + t * sin(t*rad_to_deg)));
        y = function(t) (r * (sin(t * rad_to_deg) - t * cos(t * rad_to_deg)));
        x2 = function(t) r * (cos(-t*rad_to_deg - beta) - t * sin(-t * rad_to_deg - beta));
        y2 = function(t) r * (sin(-t*rad_to_deg - beta) + t * cos(-t * rad_to_deg - beta));
        
        involute_1_points = parametric_points(fx=x, fy=y, t1=.68);
        involute_2_points = parametric_points(fx=x2, fy=y2, t1=.68);

        difference() {
            union() {
                polygon(
                    concat(
                        [[ 0, 0 ]],
                        involute_1_points,
                        reverse(involute_2_points),
                        [[ 0, 0]]
                    )
                );        
            }
            
            // Use subtraction to extend the invlute curve towards the base
            // circle and then stop it at that point. This will
            // add some square-shaped space at the base of the tooth
            // NOTE: usage of undercut might be overkill.
            circle(d=(dp - 2*b));
        }
    }

    difference() {
        circle(d=(dp + 2*a));
        circular_mirror(d=0, steps=N) involute_tooth();
    }
}

/**
    Helper modules
**/
module circular_mirror(x=0, y=0, d, steps) {
    aps = 360 / steps;
    for (step=[0:steps]) {
        current_angle = step * aps;
        unit_x = cos(current_angle);
        unit_y = sin(current_angle);
        translate([x, y, 0]) {
            translate([unit_x * d, unit_y * d, 0]) {
                rotate(current_angle) children();
            }    
        }
    }
}

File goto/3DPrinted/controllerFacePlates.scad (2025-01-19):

// Requires support, PETG-CF Black 30% fill, Smooth PEI Plate, Gluestick

plateDimensions             = [97.0, 40.0, 2.0];
plateCornerRadius           = 2.3;
plateSideCutoutLength       = 19.0;
plateSideCutoutWidth        = 1.2;

boltHoleDiameter            = 3.1;
boltHoleHeadDiameter        = 5.5;
boltHoleHeadHeight          = 1.8;
boltHoleDistanceX           = 90.0 / 2;
boltHoleDistanceY           = 32.5 / 2;

textHeight                  = 0.6;
textSize                    = 3.5;
textFont                    = "Arial:style=Bold";

screwBlockDimensions        = [12, 12, 7];
screwBlockYOffset           = -3;
m3BottomBoltDiameter        = 3.2;
m3BottomBoltHeadDiameter    = 6.2;
m3BottomBoltHeadHeight      = 2.5;
screwBlockPosXLocations     = [-35, 35];

manifoldCorrection          = 0.01;
manifoldCorrection2         = manifoldCorrection * 2;
$fn                         = 80;


plate1();
translate( [0, plateDimensions[1] + 10, 0] )
    plate2();
    
 
 
module screwBlock()
{
    translate( [0, -plateDimensions[1]/2 + screwBlockYOffset, screwBlockDimensions[1]/2] )
        rotate( [-90, 0, 0] )
            difference()
            {
                translate( [0, 0, screwBlockDimensions[2]/2] )
                    cube( screwBlockDimensions, center = true );
            
                translate( [0, 0, -manifoldCorrection] )
                    cylinder(d = m3BottomBoltDiameter, h = screwBlockDimensions[2] + manifoldCorrection2);
          
                translate( [0, 0, screwBlockDimensions[2] - m3BottomBoltHeadHeight] )
                    cylinder(d1 = m3BottomBoltDiameter, d2 = m3BottomBoltHeadDiameter, h = m3BottomBoltHeadHeight + manifoldCorrection);
    }       
}    
    
    
    
module plate1()
{
    difference()
    {
        plate();
    
        circleCutout(7.0, [13.0, 14.8], "Aux1");
        squareCutout(17.3, 16.0, [44.5, 8.44], "Dec");
        squareCutout(17.3, 16.0, [60.5, 8.44], "RA");
        squareCutout(10.1, 12.0, [77.7, 7.5], "Pwr");
    }
    
    for ( posX = screwBlockPosXLocations )
        translate( [posX, 0, 0] )
            screwBlock();
}



module plate2()
{
    difference()
    {
        plate();
        
        circleCutout(4.0, [15.5, 7.8], "Pr");
        circleCutout(4.0, [21.64, 7.8], " St");
        circleCutout(7.0, [40.5, 30.0], "WiFi");
        squareCutout(13.0, 8.0, [12.21, 17.5], "USB");
        squareCutout(16.1, 13.5, [32.5, 7.5], "Ctrl");
        squareCutout(40.0, 13.5, [48.4, 7.5], "Aux2");  
    }
    
    for ( posX = screwBlockPosXLocations )
        translate( [posX, 0, 0] )
            screwBlock();
}



module circleCutout(diameter, bottomLeftXYCenter, str)
{
    translate( [bottomLeftXYCenter[0] - plateDimensions[0] / 2, bottomLeftXYCenter[1] - plateDimensions[1] / 2, -manifoldCorrection] )
    {
        cylinder(d = diameter, h = plateDimensions[2] + manifoldCorrection2);
        translate( [-4, diameter - 1.5, plateDimensions[2] - textHeight] )
            linear_extrude( height = textHeight + manifoldCorrection2 )
                text(str, font = textFont, size = textSize);
    }   
}



module squareCutout(width, height, bottomLeftXY, str)
{
    translate( [bottomLeftXY[0] - plateDimensions[0] / 2, bottomLeftXY[1] - plateDimensions[1] / 2, -manifoldCorrection] )
    {
        cube( [width, height, plateDimensions[2] + manifoldCorrection2] );

        translate( [-4.5 + width/2, height + 1.5, plateDimensions[2] - textHeight] )
            linear_extrude( height = textHeight + manifoldCorrection2 )
                text(str, font = textFont, size = textSize);
    }
}



module plate()
{
    difference()
    {
        roundedRect(plateDimensions, plateCornerRadius);
    
        
        // Side Cutouts
        cutoutDelta = (plateDimensions[0] - plateSideCutoutWidth)/2 + manifoldCorrection;
        for ( pos = [-cutoutDelta, cutoutDelta] )
            translate( [pos, 0, plateDimensions[2]/2] )
                cube( [plateSideCutoutWidth, plateSideCutoutLength, plateDimensions[2] + manifoldCorrection2], center = true );
                
        // Bolt holes
        for ( posXY = [
                        [-boltHoleDistanceX, -boltHoleDistanceY],
                        [-boltHoleDistanceX,  boltHoleDistanceY],
                        [ boltHoleDistanceX, -boltHoleDistanceY],
                        [ boltHoleDistanceX,  boltHoleDistanceY]
                    ] )
            translate( [posXY[0], posXY[1], 0] )
                boltHole();
    }
}



module boltHole()
{
    translate( [0, 0, -manifoldCorrection] )
        cylinder(d = boltHoleDiameter, h = plateDimensions[2] + manifoldCorrection2); 
    translate( [0, 0, plateDimensions[2] - boltHoleHeadHeight] )
        cylinder(d1 = boltHoleDiameter, d2 = boltHoleHeadDiameter, h = boltHoleHeadHeight + manifoldCorrection); 
}



module roundedRect(dimensions, radius)
{
    hull()
    {
        xDelta = dimensions[0]/2 - radius; 
        yDelta = dimensions[1]/2 - radius; 
    
        for ( posXY = [
                        [-xDelta, -yDelta],
                        [-xDelta,  yDelta],
                        [ xDelta, -yDelta],
                        [ xDelta,  yDelta]
                    ] )
            translate( [posXY[0], posXY[1], 0] )
                cylinder(r = radius, h = dimensions[2]);
    }
}

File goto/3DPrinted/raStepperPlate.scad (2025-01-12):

// Print:
//     PAHT-CF
//     Smooth PEI Plate with **STICK GLUE** (not liquid)
//     Use AMS
//     Support Contacting Build Surface Only
//     100% Fill, infill pattern: Rectilinear

stepperDimensions               = [42, 42];
stepperBoltHoleDiameter         = 3.3;
stepperBoltHoleDistance         = 31.0 / 2;
stepperBoltHeadDiameter         = 5.75;
stepperBoltHeadHeight           = 5.0;
stepperPlateThickness           = 6.5;
stepperCenterVoidDiameter       = 24.0;

originalMountingHoleDiameter    = 5.0;
originalMountingHolePos         = [ [-12.7, -23.83], [-12.7, 23.83] ];

mountingBoltHeadDiameter        = 7.5;
mountingBoltHeadThickness       = 3.2;

axleCutoutOffset                = [-8, 21];
axleCutoutDimensions            = [42, 10, stepperPlateThickness];

manifoldCorrection              = 0.01;
manifoldCorrection2             = manifoldCorrection * 2;
$fn                             = 80;


raAdapterPlate();



module raAdapterPlate()
{
    difference()
    {
        outerForm();
        
        translate( [0, 0, -manifoldCorrection] )
        {
            for ( pos = originalMountingHolePos )
                translate( [pos[0], pos[1], 0] )
                {
                    cylinder(d = originalMountingHoleDiameter, h = stepperPlateThickness + manifoldCorrection2);
                    translate( [0, 0, stepperPlateThickness - mountingBoltHeadThickness + manifoldCorrection] )
                        cylinder(d = mountingBoltHeadDiameter, h = mountingBoltHeadThickness + manifoldCorrection);
                }
    
            cylinder(d = stepperCenterVoidDiameter, h = stepperPlateThickness + manifoldCorrection2);
        
            for ( pos = [
                        [-stepperBoltHoleDistance, -stepperBoltHoleDistance],
                        [ stepperBoltHoleDistance, -stepperBoltHoleDistance],
                        [-stepperBoltHoleDistance,  stepperBoltHoleDistance],
                        [ stepperBoltHoleDistance,  stepperBoltHoleDistance]
                        ] )
                translate( [pos[0], pos[1], 0] )
                {
                    cylinder(d = stepperBoltHoleDiameter, h = stepperPlateThickness + manifoldCorrection2);
                    cylinder(d = stepperBoltHeadDiameter, h = stepperBoltHeadHeight + manifoldCorrection2);
                }
        }
        
        //cube( [42, 42, 0.2], center = true);
    }
}



module outerForm()
{
    difference()
    {
        hull()
        {
            for ( pos = originalMountingHolePos )
                translate( [pos[0], pos[1], 0] )
                    cylinder(d = originalMountingHoleDiameter * 2, h = stepperPlateThickness);

            translate( [0, 0, stepperPlateThickness/2] )
                cube( [stepperDimensions[0], stepperDimensions[1], stepperPlateThickness], center = true);
        }
        
        translate( [axleCutoutOffset[0], axleCutoutOffset[1], -manifoldCorrection] )
            cube( [axleCutoutDimensions[0], axleCutoutDimensions[1], axleCutoutDimensions[2] + manifoldCorrection2] );
    }
}

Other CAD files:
pifinder/3DPrinted/PiFinderLensCover/PiFinderLensCover.3mf
dome/GPS/GPSCableClip.3mf
dome/TriBahtinovMask_ClubC14/TriBahtinovCover.3mf
goto/3DPrinted/decRJ45Plate.3mf
doors/DoorHoleFiller.scad
dome/C14SilverFinderScopeCover/C14SilverFinderScopeCover.scad
dome/CGERailEndStop/CGERailEndStop.scad
dome/GPS/GPSBracket.scad
dome/GPS/GPSBracket.stl
dome/GPS/GPSBracketCovers.3mf
dome/GPS/GPSBracketCovers.stl
dome/GPS/GPSCableClip.scad
dome/GPS/GPSCableClip.stl
dome/Power12V/Power12V.scad
dome/Power12V/Power12V.stl
dome/Sharpstar76EDPHBahtinov/Sharpstar76EDPHBahtinov.scad
dome/Sharpstar76EDPHBahtinov/Sharpstar76EDPHBahtinov.stl
dome/TriBahtinovMask_ClubC14/TriBahtinovCover.stl
dome/TriBahtinovMask_ClubC14/TriBahtinovMask.3mf
dome/TriBahtinovMask_ClubC14/TriBahtinovMask.scad
dome/TriBahtinovMask_ClubC14/TriBahtinovMask.stl
dome/ZWOCameraCoverGromit/ZWOCameraCoverGromit.scad
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

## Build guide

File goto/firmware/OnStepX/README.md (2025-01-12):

OnStepX Telescope Controller
===========================

# What is OnStepX?
OnStepX is the advanced version of the OnStep computerized telescope controller with support for interfacing with/controlling a variety of motor drivers (and so motors) including Step/Dir, ODrive, and Servo (a combination of encoder and DC motor or Stepper motor) types.

It supports:
* Telescope Mount control (Alt/Azm and Equatorial GEM/Fork.)  Optional support for Eq mounts with Tangent Arm Declination.  Usually the Goto capability is enabled, but that's optional as well for those who just want basic mount control.
* Telescope Rotator control (including Alt/Azm de-rotation.)
* Telescope Focuser control (up to 6 focusers so it can handle collimation as well as focusing.)
* Telescope Accessory control (combination of up to 8 dew-heaters, switches, analog PWM.)

# Features
OnStepX supports a wide variety of connection options.  Several serial
"command channels" can be utilized. One of the these is normally devoted to a USB
connection and for the other(s) choose from the following:

* Bluetooth
* ESP8266 WiFi
* Arduino M0/Ethernet Shield
* Even another USB port or RS232 serial isn't very difficult to add.

In the case of running OnStepX on an ESP32 it can provide its own Bluetooth or WiFi IP command channels without additional hardware by simply activating the feature in OnStepX.

Other software in the OnStep ecosystem include:

* an [ASCOM](http://ascom-standards.org/) driver (with IP and Serial support),
* an Android App useable over WiFi or Bluetooth equipped Phones/Tablets,
* a "built-in" website (on the Ethernet and/or WiFi device),
* a full planetarium program that controls all features ([Sky Planetarium](http://stellarjourney.com/index.php?r=site/software_sky)).

OnStep is compatible with the LX200 protocol. This means it can be controlled
from other planetarium software, like: Sky Safari, CdC (even without ASCOM),
Stellarium, etc.

There are also [INDI](http://www.indilib.org/about.html) drivers so it can be used from Linux, with CdC or KStars.

# Documentation
Detailed documentation, including the full set of features, detailed designs for
PCBs, instructions on how to build a controller, how to configure the firmware
for your particular mount, can all be found the [OnStep Group Wiki](https://groups.io/g/onstep/wiki/home).

# Change Log
All the changes are tracking in git, and a detailed list can be accessed using the
following git command:
 
git log --date=short --pretty=format:"%h %ad %<(20)%an %<(150,trunc)%s"

# Support
Questions and discussion should be on the mailing list (also accessible via the
web) at the [OnStep Group](https://groups.io/g/onstep/).

# License
OnStep is open source free software, licensed under the GPL.

See [LICENSE.txt](./LICENSE.txt) file.

# Author
[Howard Dutton](http://www.stellarjourney.com)

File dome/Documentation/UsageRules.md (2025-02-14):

# Usage Rules

Access to the Wilson Coulee dome, is a privilege available to members in good standing who have been with the club for a while and known to the committee members for a period.  A requirement for access is that the user is trained/checked out on the equipment, is careful in the handling of the equipment, and follows the procedures for its operation.

The C14 is used for tours, the youth group, and other events and is a shared resource.  Damage to the C14 results in the telescope being out of commission, which directly impacts the club's operations.  To ensure this doesn’t happen, it’s necessary to have rules for its use which members are required to adhere to.

There are two levels of dome usage, Visual and Astrophotography, and training and verification of your skills are required for both.

SkyPilot is a new custom goto, and the occasional gremlins/bugs should be expected. Please notify Mark Simpson or the site manager of any operational issues.

### Visual

Visual use ONLY of the C14. Capabilities are:

* Goto with SkyPilot
* Hand Controller
* Control via SkySafari on your phone or tablet
* Visual lenses and focuser
* Finder Scopes: Telrad, Silver Finderscope

###### It's is not permitted with this level of access to use for Astrophotography (including using your own astrophotography gear or cameras)

### Astrophotography

This level of access includes the visual level, provides access to use the club's Astrophotography gear as well as attaching your own gear, including DSLRs/Cameras.

Capabilities are:

* Bring Your Own Astrophotography Gear
* Auto Guiding
* OSC APS-C Sensor
* Narrowband Filters
* C14 and Widefield Imaging (3910mm, 2400mm and 342mm focal lengths)

# Equipment Rules and Usage

* [General](#general)
* [SkyPilot (Goto)](#skypilot-goto)
* [SkyPilot (Handset)](#skypilot-handset)
* [Sky Safari](#sky-safari)
* [ASIAIR](#asiair)
* [Bring Your Own Astrophotography Gear or Laptop](#bring-your-own-astrophotography-gear-or-laptop)
* [Flat Panel](#flat-panel)
* [Filters](#filters)
* [Usage Patterns](#usage-patterns)

## General

### Rules:

#### DO NOT:

* Adjust any equipment, alignment, modify, rotate, remove (even temporarily), clean lenses/filters/sensors, without prior authorization of the Site Manager.  This includes the guide/finder scopes, cameras, and Telrad.
* Place club equipment on the pier (where it can fall) or on the shelf near the trash can (where it can fall into the trash can).
* Remove any equipment from the dome, including the Flat Panel, Cameras, Filters and do NOT use any of the equipment on any scopes other than the C14. The equipment is only for use on the C14.

## SkyPilot (Goto)

### Rules:

#### DO NOT:
* Attempt to move the OTA manually or apply pressure in Declination when attaching equipment to avoid increasing drive backlash or damage. C14 cover must ALWAYS be placed lightly on the OTA
* Connect anything by wire to the SkyPilot controller mounted on the mount base. This includes the USB and ST4 ports (which will damage your equipment and SkyPilot)
* Connect your own laptop or device to any of the club's equipment. (Wifi is the only way to control the mount)
* Use SkyPilot outside of the temperature limits specified
* Disconnect any wires during operation. Drivers will be damaged if unplugged during operation due to surge.

#### DO:

* Move the scope with the electronic control only
* Power off by removing the main power plug from the power outlet on the pier when leaving. A scope left on will continue to move and cause damage

#### ALWAYS:
* Park the scope via the PARK menu option when shutting down the dome
* Be in the dome during any goto operation.  Under no circumstances should a goto be done from outside the dome or in the clubhouse
* Carefully watch any goto and stop the operation if damage is imminent. Attention must be paid to the stairs being too close to the mount, wires, cable wrapping, equipment, cameras/gear hitting the forks or base, and people around the telescope

### Usage:

1. Plug main power into the pier socket on entry to the dome (it takes a few minutes for SkyPilot to boot up WiFi)
2. Open dome
3. Connect to WCODome\_2.4G or WCODome\_5G with your phone or tablet
4. Switch on Hand Controller
5. Set RA to zero (loosen the RA clutches, move and retighten).  OTA should be pointing south.
6. On Hand Controller, UNPARK
7. Slew to position and complete a 1 star align to increase pointing accuracy/register telescope pointing model:
	
	Hand Controller:
	
	* Use joystick on hand controller to slew and center target
	
	SkySafari:
		
	* Tap on target (star or planet)
	* Tap Goto
	* Center target in finderscope using SkySafari or hand controller Joystick controls
	* Tap Align

	ASIAIR:
	
	* Switch ASIAIR on
	* Connect via app
	* Take photo
	* Tap Platesolve
	* Tap Sync and Goto
	* Take photo (target should be centered)
	* ALWAYS SHUTDOWN ASIAIR before switching off / removing power to avoid corruption

	ASTRID:
	
	* Switch ASTRID on
	* Switch to Dome Wifi network
	* Take photo
	* Tap Platesolve
	* Tap Sync and Goto
	* Take photo (target should be centered)
	* ALWAYS SHUTDOWN ASTRID before switching off / removing power

### Temperature Limits:

These may be changed as we test:

* < -20C:	Scope cannot be used due to potential for dome slit to jamb

Note: "Insane Mode" can only be used > 0C

If the temperature limit is inappropriate for the slew rate, the steppers will stall on goto, make a whining noisem, and position will be lost, you will then need to do a 1 star align to be able to goto and park.

### Troubleshooting:

#### Unable to communicate with mount:

1. Check your device is on the dome wifi
2. Check wifi router (south wall) has green lights
3. Power cycle SkyPilot mount (pull power plug, wait 10 seconds and reinsert), then when reconnected do a 1 star alignment

#### Unable to move mount:

1. Mount has software limits and you may have hit one.  Try slewing the mount with the hand controller joystick in various directions to move away from the limit and then complete a 1 star alignment so the mount knows where it is

## SkyPilot (Handset)

### Rules:

#### DO NOT:

* Connect anything to the USB-C port on the handset.  It is only for programming and will most likely damage your device and the hand controller
* Place the hand controller anywhere other than around your neck or in its permanent storage location. The hand controller will break if dropped. DO NOT rest the hand controller on the pier.

#### DO:

* Always use the hand controller with the lanyard over your neck. This ensures it cannot fall.
* Switch off the hand controller when you have finished your observing session, or if you won't be using it for a while (for example because you are using the ASIAIR) to save battery
* Replace batteries when necessary

### Usage:

1. Put handset around neck
2. Power on handset
3. Wait for connection
4. 	Unpark (ASIAIR/SkySafari will not move the scope if you don't unpark)
5. Use joystick mode to slew if required
6. Power off handset if not using to save battery (i.e. in clubhouse, using the ASIAIR platesolving)
7. When finished, switch on handset (if off), and Park scope, wait for it to finish returning to the park position
8. Power off handset

### Buttons:

(buttons need to be fully depressed)
	
* 4 Black Buttons are the joystick (N,S,E,W):
	1. In menu mode, you use these to navigate the menu
	2. In joystick mode you use these to slew the scope.
* Yellow Button toggles between menu mode and joystick mode

* F1 = Blue Button, F2 = White Button.  In joystick mode, F1 decreases the slew rate and F2 increases the slew rate

### Troubleshooting:

#### White error text on display

If you are in the dome and see white text on the display (i.e. not weak wifi), then take a photo of the text and send to Mark.  Then power cycle the handset to recover.

#### Warning about low power or power drop

Replace batteries

#### Hand controller frozen

Power cycle hand controller.  If that doesn't fix it, switch off the hand controller, power cycle SkyPilot mount, switch on the hand controller, and wait for the connection.

#### Site Manager Only

*Only for Site Manager Use. There is a pointing model that has been created that will be lost if you enter this menu, and pointing will be degraded*

For access to Site Manager menu, hold F1 and F2 and press W button to enter menu.

##### 3-Star Alignment

1. Unpark
2. With Sky-Safari, "Goto a star (or planet)", center star in silver finder scope using joystick and Click Align.  Use a star away from NCP and not too close to the ground.
3. Enter 3 Star Align menu item (position in Sky Safari now moves to NCP)
4. Click on the original target in 2., and click Align to return the bullseye to the target in 2.  The 1st star has now been entered.
5. Locate a 2nd star, away from the 1st star, click it and click Goto.  Center star in silver finder scope using joystick and Click Align.  The 2nd star has now been entered.
6. Locate a 3rd star, away from the 1st star, click it and click Goto.  Center star in silver finder scope using joystick and Click Align.  The 2nd star has now been entered.

Pointing model has now been updated.  OnStepX web browser will say "Complete" in the Align panel and have the amount of offset for the pointing model (Mount relative to NCP).  If it is ever zero, then the pointing model has been lost.  It can be reset by just choosing 3 Star Align (but not entering stars), and Park and Unpark.

## Sky Safari

SkySafari Plus or Pro (available on tablet and phone for iOS or Android) will connect wirelessly with the SkyPilot goto controller.  Note: SkySafari regular (Basic) does not have telescope control.

To control SkyPilot via Sky Safari, you must setup the connection as follows in SkySafari:

1. Menu / Settings / Telescope / Presets / Add Preset
2. Other
3. Mount Type: Equatorial GoTo (Fork)
4. Scope Type: Meade LX200 Classic
5. (Tap Next)
6. IP Address: 192.168.1.200
7. Port Number: 9999
8. Preset Name: WCO SkyPilot
9. Set Telescope Time & Location: THIS MUST BE SWITCHED OFF!
10. Readout Rate: 4 per second
11. Timeout Seconds: 3.0
12. Tap "Save Preset"
13. Select the new preset, so that it's checkmarked
14. Tap the cross (top right) to return to the planetarium view
15. Click "Scope" and "Connect

#### Usage:

1. SkyPilot should be powered on
2. Connect to Dome Wifi
3. Start Sky Safari
4. Tap Scope
5. Tap Connect
6. Tap object and then Goto to slew to that object
7. If the object isn't centered in the silver finder scope, then center with the SkySafari arrows or the handset joystick and tap "Align" in SkySafari to sync the current position to the target position.

## ASIAIR

The ASIAIR can be used for platesolving provided the 2600MC Pro camera is attached to the C14 or Widefield scope.  The ASIAIR software can be downloaded for free from the Apple or Google Appstore on your iPhone, Android or Tablet.

### DO NOT:

* Change settings on the ASIAIR other than the ones listed below
* Do not retrain the Autoguider or change Autoguiding settings
* Do not plug in your own astrophotography equipment to the ASIAIR
* Connect your laptop to the ASIAIR

### DO:

* Control the ASIAIR via the ASIAIR app on your phone. If you don't have this app, do not power on the ASIAIR
* Shutdown the ASIAIR before removing power to avoid corruption
* After shutdown, wait 15 seconds and switch off ASIAIR on rocker switch on the bottom

### Usage:

* Plug in the 12V power supply to the power outlet (the 12V power supply is the smaller blue power supply)
* Switch the ASIAIR on (small power switch on the bottom)
* Wait for the beep to indicate it's ready to go (can take a minute or so)
* Connect your iPhone/tablet to the dome's Wifi
* Start the ASIAIR app
* If the ASIAIR isn't showing, click Scan
* Tap Connect when ASIAIR shows
* Make sure the ASIAIR is in preview mode
* Take photo (white button) - 5 second exposure is good for a plate solve, if you have cloud, then you may want to try 10-30s).
* Tap Plate Solve on the left
* Tap Sync and Goto
* Take another photo if you wish to verify you're in the correct location
* Now you can use the Sky Atlas (constellation button in the bottom left hand corner), to move around the sky.  Remember to Photo, PlateSolve and Sync/Goto to be perfectly positioned on the new target
* REMEMBER TO SHUTDOWN WHEN YOU ARE DONE FOR THE EVENING, BEFORE REMOVING POWER:
	* Tap the Wifi Icon, scroll to the bottom and there's a red button you slide to the right to shutdown.  Wait 30 seconds before removing power.

### Troubleshooting:

#### No ASIAIR listed to connect to

* ASIAIR has no power or isn't switched on
* You are not connected to the dome's Wifi network

#### No PlateSolve

* Cloud, expose longer

#### Camera Not Found

* Camera on the Orion ST80 has a magentic attachment, check the cable is attached to this
* Tap icon that looks like a camera, find the camera in the list (ASI174MM), select it and switch it on.  DO NOT CHANGE ANY SETTINGS.

## Bring Your Own Astrophotography Gear or Laptop

**You must have the Astrophotography level of access training before attaching your own gear including any cameras or DSLR**

### Rules:

#### DO NOT:

* Attach / piggyback a DSLR, Camera or Other equipment to any of the rails or Optical Tube. (there are equatorial platforms available for rent for DSLRs via the club’s rental program)
* Connect a laptop or other device to any of the clubs equipment, other than over Wifi
* Change any settings on the ASIAIR
* Use any gear belonging to the club with your devices, i.e. do not connect any of the clubs cameras to your laptop for example
* Attach any cameras to the Widefield scope other than the clubs OSC Camera

#### DO

* You may attach a camera to the visual back of the C14 ONLY (i.e. where the eyepiece goes), if you have the correct mating adapter and are careful not to damage the threads on the visual back
* Replace the visual train on the visual back after use, ready for the next person

## Flat Panel

The flat panel is expensive and easily damaged if not careful.

### Rules:

#### DO NOT:

* Remove or use outside the dome. The flat panel is only for the C14.
* Use the flat panel when the OTA is pointing below 20 degrees elevation (it can fall and will break)

#### DO:

* Always cover with the protective cover and put away in the cupboard when not actively taking a flat field
* Be careful when using to avoiding scratching surface
* Do not clean, it scratches easily. If it needs cleaning, contact the Site Manager

#### Usage:

* Position OTA so that it is angled about 20 degrees up from horizontal (so the panel can't fall)
* Place panel onto rim of the OTA, being careful not to damage the flat panel surface with the rim
* Connect 12V DC Power from the pier to the flat panel
* Take flats (only necessary to take 5 images optimized for about 30% on the histogram)

## Filters

The filters are expensive ($450) a piece and are useless if accidentally scratched or damaged.

### Askar ColorMagic D1:

Narrowband Ha and OIII, reduced halos on bright stars

### Askar ColorMagic D2:

Narrowband SII and OIII, reduced halos on bright stars

### OptoLong L-Extreme

Narrowband Ha and OIII

### Rules:

#### DO NOT:

* Blow on filters, spit is acid, will etch filters and is impossible to clean off once set in
* Clean filters, contact site manager if a filter needs cleaning
* Store filter outside of filter container. Place immediately in container. This avoids dust which impacts imaging.
* Put filter in at an angle into cases and filter drawers, it's possible to scratch the filter with the case.

# Usage Patterns

## Visual Only

* Output: Focuser/Lenses attached to Visual Back
* Control: SkyPilot Hand Controller and SkySafari(optional)
* Fine Positioning: Telrad and Silver Finderscope
* Autoguiding: No
* Camera: None
* Camera Filter: None

## Visual Only (with Platesolving via ASIAIR)

* Output: Focuser/Lenses attached to Visual Back
* Control: SkyPilot Hand Controller and ASIAIR
* Fine Positioning: Platesolving
* Autoguiding: No
* Camera: None
* Camera Filter: None

## Visual Tour and Accessibility

* Output: Focuser/Lenses attached to Visual Back and streaming widefield scope to ClubHouse TV and TV in dome
* Control: SkyPilot Hand Controller and ASIAIR
* Fine Positioning: Platesolving (ASIAIR) via the 2600MC Pro
* Autoguiding: Yes (needed for Live Stacking), on Orion ST80
* Camera: 2600MC Pro on widefield scope
* Camera Filter: OSC Narrowband (for planetary/emission nebula) or regular broadband (no filter) - (galaxies/reflection nebula)

## Astrophotography @ 3910mm, f6.3 focal reducer (optional)

* Output: 2600MC Pro attached to visual back and streaming/control to users phone/tablet. (note clubhouse TV/dome TV are an option here but no control)
* Control: SkyPilot Hand Controller and ASIAIR
* Fine Positioning: Platesolving (ASIAIR) via the 2600MC Pro
* Autoguiding: Yes, on Orion ST80
* Camera: 2600MC Pro on visual back
* Camera Filter: OSC Narrowband (for planetary/emission nebula) or regular broadband (no filter) - (galaxies/reflection nebula)

## Astrophotography Widefield

* Output: 2600MC Pro attached to piggybacked widefield astrograph and streaming/control to users phone/tablet. (note clubhouse TV/dome TV are an option here but no control)
* Control: SkyPilot Hand Controller and ASIAIR
* Fine Positioning: Platesolving (ASIAIR) via the 2600MC Pro
* Autoguiding: Yes, on Orion ST80
* Camera: 2600MC Pro on widefield astrograph
* Camera Filter: OSC Narrowband (for planetary/emission nebula) or regular broadband (no filter) - (galaxies/reflection nebula)

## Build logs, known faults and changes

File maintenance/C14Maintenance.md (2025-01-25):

# C14 Maintenance

## RA Drive

1. Remove the 6 bolted black bearing axle holder on the right hand outside of the RA casing (be careful, when tightening later, one of the bolts has already been stripped

2. Back-off the right0hand grub screw (in a pair on the left-hand side of the worm axle), it's spring-loaded

3. Slide the axle to the right and remove it.  IMPORTANT, there's a single bearing that's just held in by grease surface tension on the left-hand side (where the bronze bearing is), remove and store it safely for later, when the axle is removed, OTA will fall down to the lowest gravity point, mind your head

4. Unbolt the stepper motor and remove

5. Use the electrical degreaser in the basement with "blue shop towel", to clean the worm axle and large RA gear in the C14 and the aluminimum gear on the worm axle, DO NOT use the degreaser on the nylon gear on the stepper.  Wipe off all the degreaser.

6. Remove the brass bushing/bearing from the worm axle and inspect where it joins for rubbing after degreasing.  It's a tight push fit and just needs to be pulled apart

7. Clean nylon stepper gear with shop towel, inspect for wear and replace if necessary

8. ONLY USE SuperLube for the grease (white lithium separates over time and doesn't handle the speeds necessary or cold well).  Lube the worm, the brass bushing, the alumninum gear on the worm axle, and the main large RA gear.  Also lube the nylon gear on the stepper

9. Put grease in the end of the axle and place the ball bearing.  On the ball bearing holder on the right hand side, put a bit of grease inside

10. Reassemble

11. Adjust the left hand spring tension on the brass bushing via the grub screw so that the rotation isn't restricted with too much friction

12. Adjust the bolt post on the left hand black bearing holder in the center if needed to tighten up any left/right movement of the axle, i.e. this is a backlash adjustment for RA

13. Test at goto slew speeds

## DEC Drive

Ordinarily, the DEC shouldn't need much maintenance as the Strainwave/Harmonic Drive gear is enclosed and there's no lubrication needed anywhere.  Therefore, this just contains instructions for disassembly in case there are any failures that need repairing.

Gearing is 400:1 with the strainwave gear being 100:1 and a 4:1 stepper to strainwave input gearing.

1. Remove outer casing using an Allen key to reveal the stepper motor, drive axle and belts
2. Inspect stepper belt for wear
3.	Unscrew the DEC Movement Indicator
4. 	Insert the 1/4 - 20 threaded rod with 2 nuts on into the bronze axle and screw in (don't tighten).  Attach electric drill to this thread in a clockwise motion and rotate via the drill to line up the bolts to the gap in the housing for removal.
5. Remove the plate to plate connector bolts (the OTA will fall with the last bolt removal)
6. With the drill running anticlockwise, unscrew the threaded rod
7. Remove the bolts that attach the housing to the telescope
8. Remove the central nuts and fender washer
9. Remove the 4 bolts attaching the plate to the hub
10. Remove the center bolt and the 2 outside bolts to free the hub from the DEC bearing

Reassembly is the reverse of disassembly.

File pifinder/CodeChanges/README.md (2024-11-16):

Source: https://github.com/brickbots/PiFinder

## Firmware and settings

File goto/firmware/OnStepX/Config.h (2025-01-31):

/* ---------------------------------------------------------------------------------------------------------------------------------
 * Configuration for OnStepX
 *
 *          For more information on setting OnStep up see http://www.stellarjourney.com/index.php?r=site/equipment_onstep 
 *                      and join the OnStep Groups.io at https://groups.io/g/onstep
 * 
 *           *** Read the compiler warnings and errors, they are there to help guard against invalid configurations ***
 *
 * ---------------------------------------------------------------------------------------------------------------------------------
 * ADJUST THE FOLLOWING TO CONFIGURE YOUR CONTROLLER FEATURES ----------------------------------------------------------------------
 * <-Req'd = always must set, <-Often = usually must set, Option = optional, Adjust = adjust as req'd, Infreq = infrequently changed
*/
//      Parameter Name              Value   Default  Notes                                                                      Hint

// =================================================================================================================================
// CONTROLLER ======================================================================================================================

// PINMAP ------------------------------------------------- see https://onstep.groups.io/g/main/wiki/Configuration_Controller#PINMAP
#define PINMAP                        MaxPCB4 //    OFF, Choose from: MiniPCB, MiniPCB2, MaxPCB2, MaxESP3, CNC3, STM32Blue,      <-Req'd
                                          //         MaxSTM3, FYSETC_S6_2, etc.  Other boards and more info. in ~/src/Constants.h

// SERIAL PORT COMMAND CHANNELS --------------------- see https://onstep.groups.io/g/main/wiki/Configuration_Controller#SERIAL_PORTS
#define SERIAL_A_BAUD_DEFAULT        9600 //   9600, n. Where n=9600,19200,57600,115200,230400,460800 (common baud rates.)    Infreq
#define SERIAL_B_BAUD_DEFAULT        9600 //   9600, n. Baud rate as above. See (src/pinmaps/) for Serial port assignments.   Infreq
#define SERIAL_B_ESP_FLASHING         OFF //    OFF, ON Upload ESP8266 WiFi firmware through SERIAL_B with :ESPFLASH# cmd.    Option
#define SERIAL_C_BAUD_DEFAULT         OFF //    OFF, n. Baud rate as above. See (src/pinmaps/) for Serial port assignments.   Infreq
#define SERIAL_D_BAUD_DEFAULT         OFF //    OFF, n. Baud rate as above. See (src/pinmaps/) for Serial port assignments.   Infreq
#define SERIAL_E_BAUD_DEFAULT         OFF //    OFF, n. Baud rate as above. See (src/pinmaps/) for Serial port assignments.   Infreq
#define SERIAL_RADIO                  OFF //    OFF, Use BLUETOOTH or WIFI_ACCESS_POINT or WIFI_STATION (ESP32 only.)         Option

// STATUS --------------------------------------------- see https://onstep.groups.io/g/main/wiki/Configuration_Controller#STATUS_LED
#define STATUS_LED                    OFF //    OFF, Steady illumination if no error, blinks w/error code otherwise.          Option

// RETICLE CONTROL ------------------------------- see https://onstep.groups.io/g/main/wiki/Configuration_Controller#RETICLE_CONTROL
#define RETICLE_LED_DEFAULT           OFF //    OFF, n. Where n=0..255 (0..100%) activates feature sets default brightness.   Option
#define RETICLE_LED_MEMORY            OFF //    OFF, ON Remember reticle brightness across power cycles.                      Option
#define RETICLE_LED_INVERT            OFF //    OFF, ON Inverts control for cases where 0V is max brightness.                 Option

// WEATHER SENSOR --------------------------------- see https://onstep.groups.io/g/main/wiki/Configuration_Controller#WEATHER_SENSOR
#define WEATHER                       OFF //    OFF, BME280 (I2C 0x77,) BME280_0x76, BME280_SPI (see pinmap for CS.)          Option
                                          //         BMP280 (I2C 0x77,) BMP280_0x76, BMP280_SPI (see pinmap for CS.)
                                          //         BME280 or BMP280 for temperature, pressure.  BME280 for humidity also.

// SIGNALING ------------------------------------------- see https://onstep.groups.io/g/main/wiki/Configuration_Controller#SIGNALING
#define STEP_WAVE_FORM             SQUARE // SQUARE, PULSE Step signal wave form faster rates. SQUARE best signal integrity.  Adjust
                                          //         Applies to all axes.

// NON-VOLATILE MEMORY ---------------------------------------- see https://onstep.groups.io/g/main/wiki/Configuration_Controller#NV
#define NV_DRIVER              NV_DEFAULT // NV_DEF, Use platforms default non-volatile device to remember runtime settings.  Option

// =================================================================================================================================
// MOUNT ===========================================================================================================================
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

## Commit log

2024-11-11 Updating documentation
    [GPSBracket.3mf, GPSBracket.scad, GPSBracket.stl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]
2024-11-16 Adding pifinder
    [C14FinderHolder.scad, C14PiFinderHolder.3mf, PiFinder.3mf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]
2025-01-12 Adding firmware and 3D printing
    [DoorHoleFiller.3mf, DoorHoleFiller.scad, DoorHoleFiller.stl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]
2025-01-19 Updating 3D printed files and firmware
    [byersCaseExtension.3mf, byersCaseExtension.scad, byersCaseExtension.stl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]
2025-01-22 Adding 3D prints and changing settings
    [byersDriveGear.3mf, byersDriveGear.scad, byersDriveGear.stl]
2025-02-14 Adding 3DPrint9ing and updating Receipts and Donations
    [C14SilverFinderScopeCover.scad, C14SilverFinderScopeCover.stl, CGERailEndStop.scad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]
